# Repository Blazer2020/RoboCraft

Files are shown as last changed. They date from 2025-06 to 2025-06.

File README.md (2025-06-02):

# 🤖 Autonomous Robot – Robot Design Module

This project features an autonomous mobile robot developed by **Team RoboCraft** for the **Hawkins Interdimensional Challenge 2024**, hosted by the Department of Electronic and Telecommunication Engineering, University of Moratuwa.

The robot was designed to complete a series of 8 challenging tasks involving line following, color tracking, box manipulation, portal navigation, and terrain traversal — all under fully autonomous control. Built using an Arduino Mega, JGA25 encoder motors, Reykha IR sensor array, and a 3D-printed chassis, the robot runs on an onboard 11.1V Li-ion battery and uses intelligent decision-making to adapt to each task without any external input.

---

## 🛠 Robot Overview

| Component | Specification |
|---|---|
| **Microcontroller** | Arduino Mega 2560 |
| **Motors** | JGA25 DC Encoder Motors (×2) |
| **Motor Driver** | L298N Dual H-Bridge |
| **Gripper** | SG90 Servo Motor |
| **Chassis** | 3D Printed Body (240mm × 180mm footprint) |
| **Sensors** | Reykha Analog IR Line Sensor Array |
| **Battery** | 11.1V 400mAh Li-ion Battery (onboard power) |
| **Indicators** | Onboard LEDs (task status and feedback) |

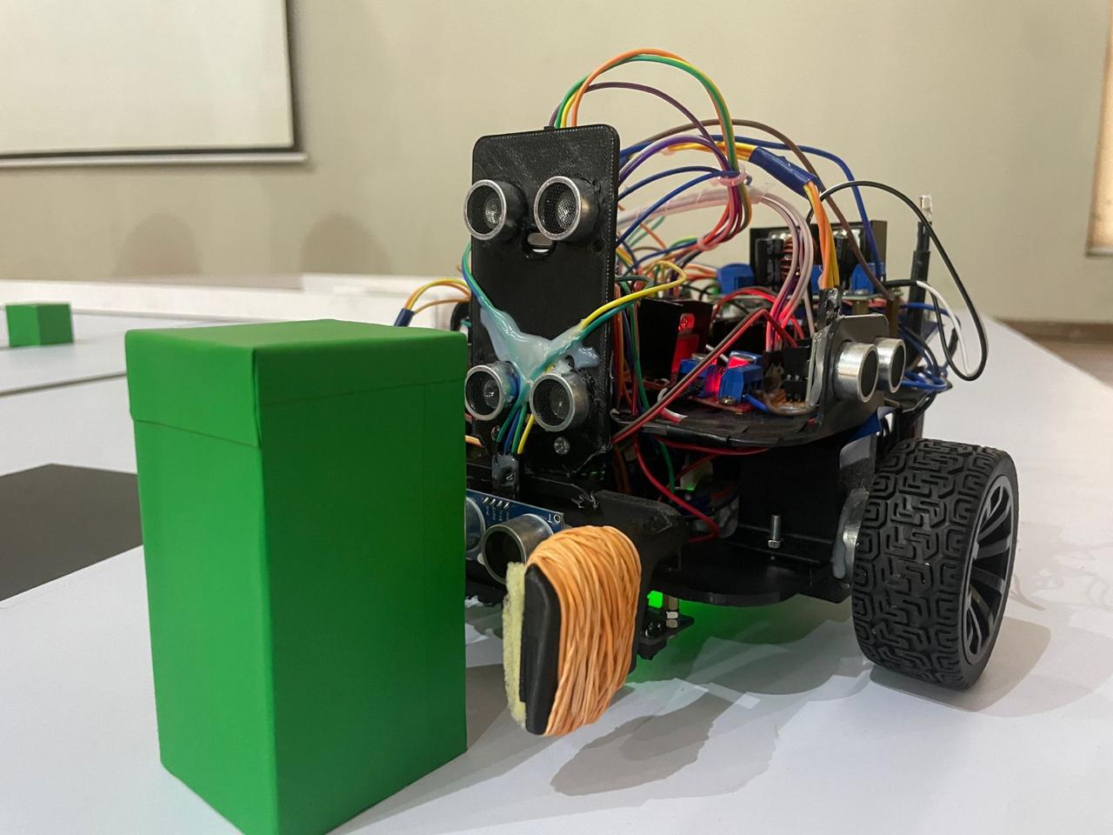
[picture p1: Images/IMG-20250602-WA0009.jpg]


---

## 🎯 Challenge Tasks

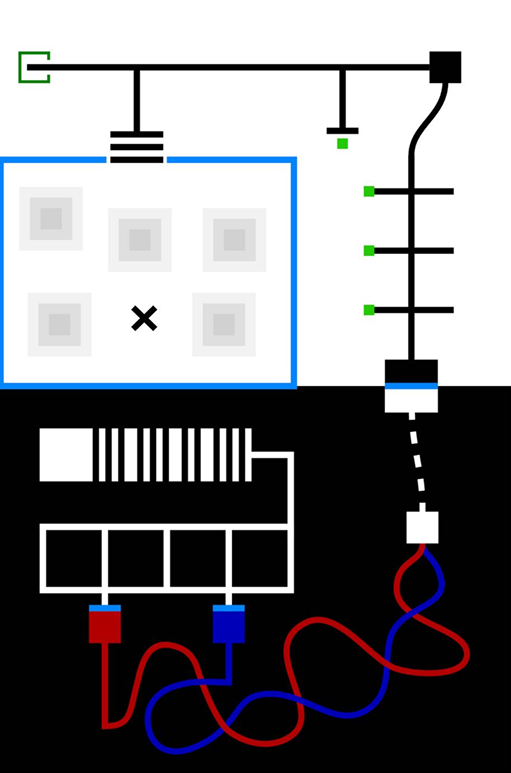
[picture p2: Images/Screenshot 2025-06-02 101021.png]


| Task No. | Task Name | Description |
|---|---|---|
| **1** | Line Width Detection | Follow white lines of varying widths (3cm = 0, 6cm = 1) to extract a binary code |
| **2** | Virtual Box Maze Navigation | Simulate grabbing and transporting a virtual box with restricted movement |
| **3** | Color Line Following | Follow Red or Blue line based on the checkpoint from Task 2 |
| **4** | Dashed Line Navigation | Track a dashed white line leading to the portal area |
| **5** | Portal Timing Challenge | Time movement to pass through a 5s open/5s close gate without collision |
| **6** | Box Sorting | Arrange boxes of different heights in order (asc/desc based on prior path) |
| **7** | Box Insertion | Follow a line to insert a small box into a chamber hole |
| **8** | Coin Drop on Magnetic Spot | Drop a 2-rupee coin on an ‘X’ mark over uneven terrain to complete the run |

---

## 🧩 SolidWorks Model Previews

The robot's mechanical structure was designed in **SolidWorks** to ensure precise fitting of components and smooth task execution. Below are some rendered previews from the CAD models.

| View | Preview |
|---|---|
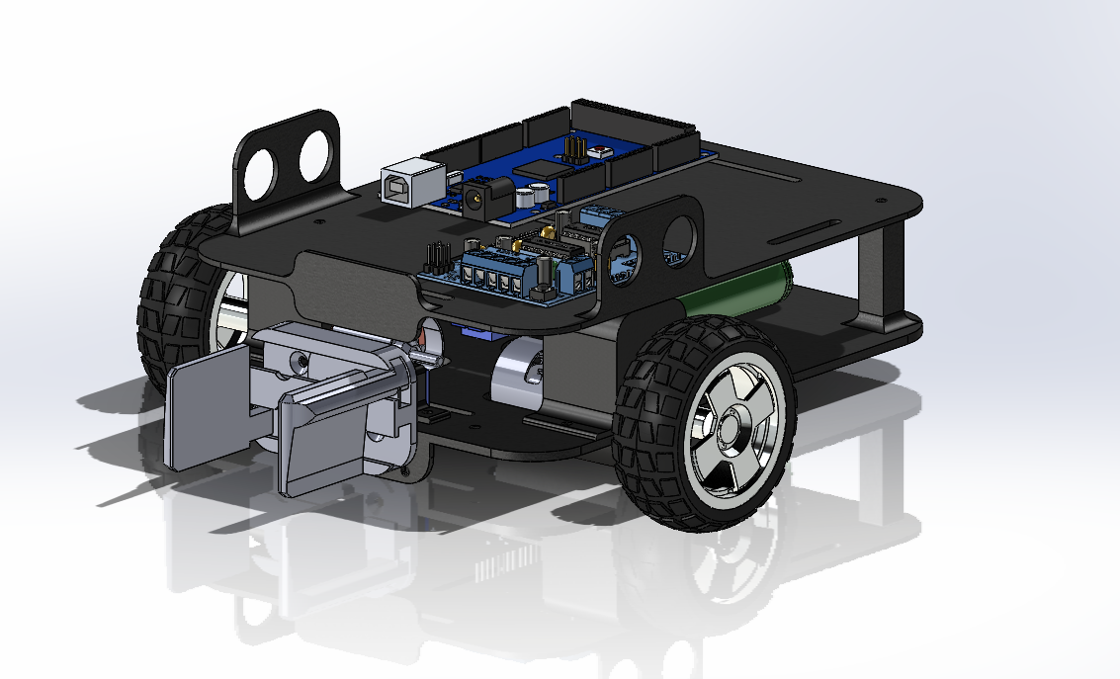
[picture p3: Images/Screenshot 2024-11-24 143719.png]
| **Front View** |   |
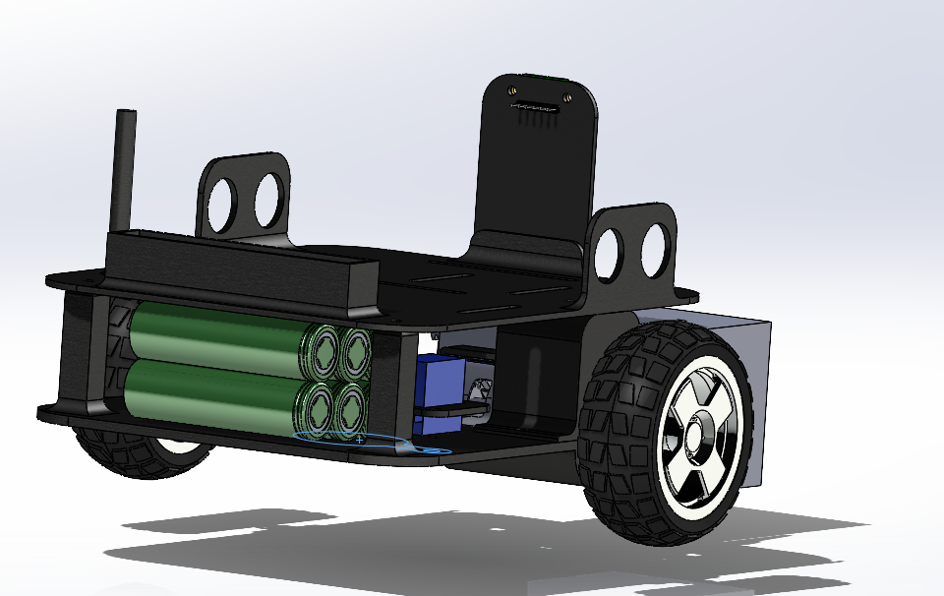
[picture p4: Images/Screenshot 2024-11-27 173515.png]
| **Rear View** |  |
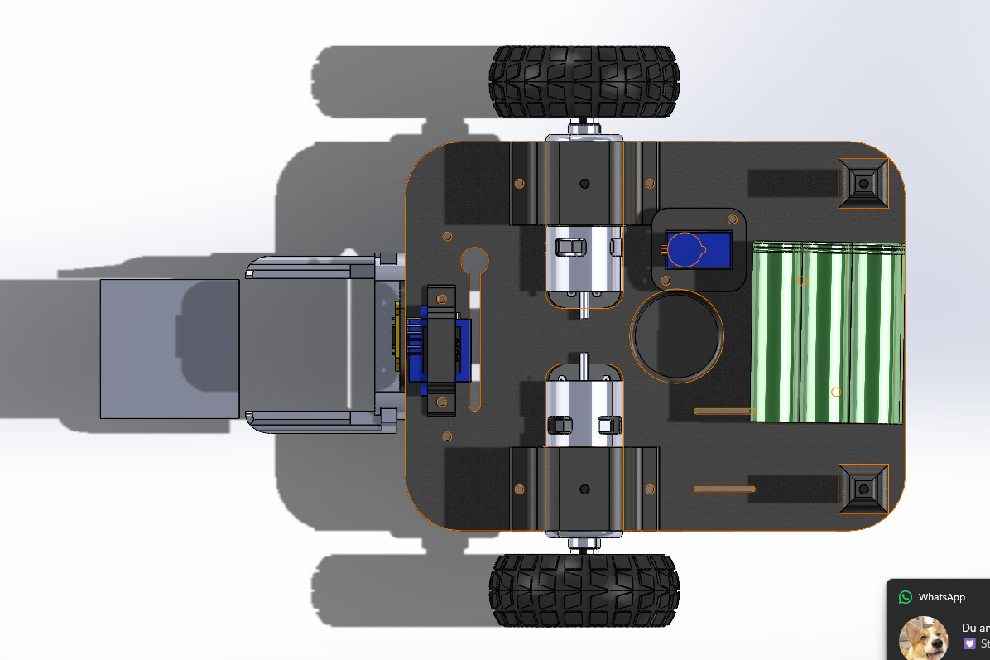
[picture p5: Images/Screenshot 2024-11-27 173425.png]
| **Top View** |  |
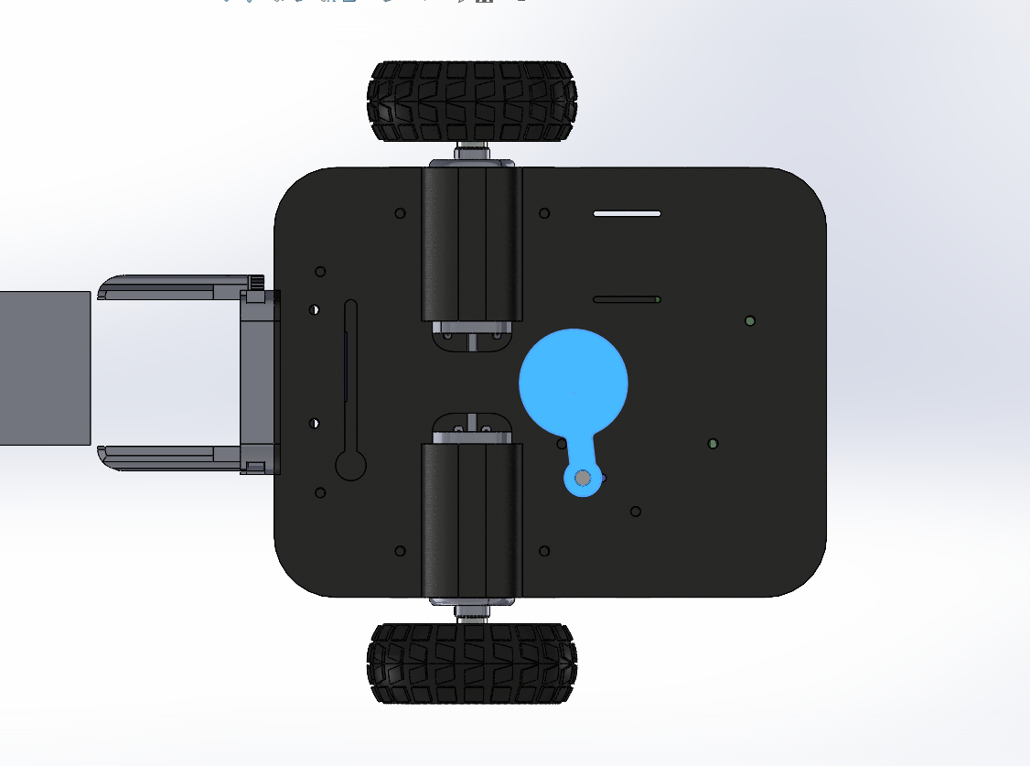
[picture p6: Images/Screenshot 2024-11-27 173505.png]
| **Bottom View** |  |
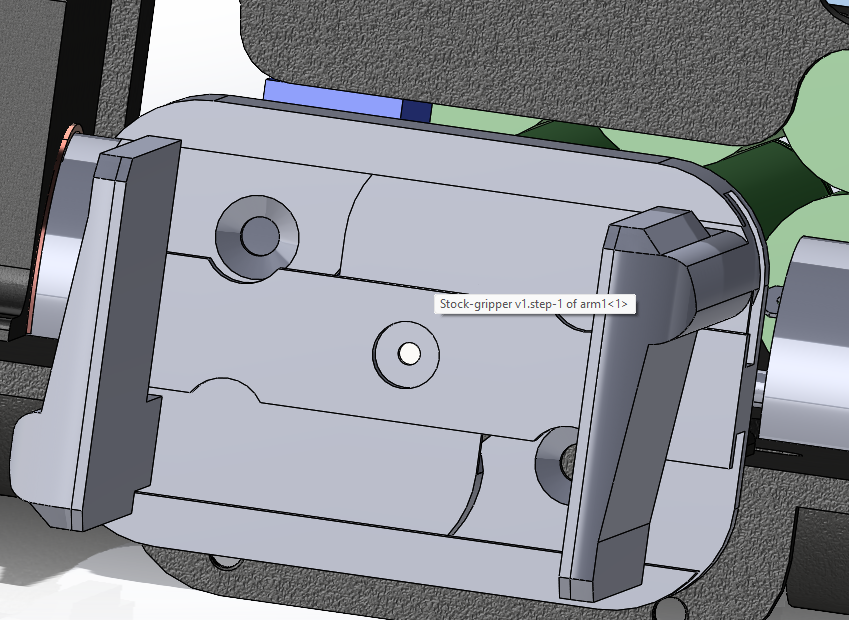
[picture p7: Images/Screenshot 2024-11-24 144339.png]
| **Gripper Design** |   |

> STL files and full CAD assemblies are available in the [`/STL files`](./STL files) folder.

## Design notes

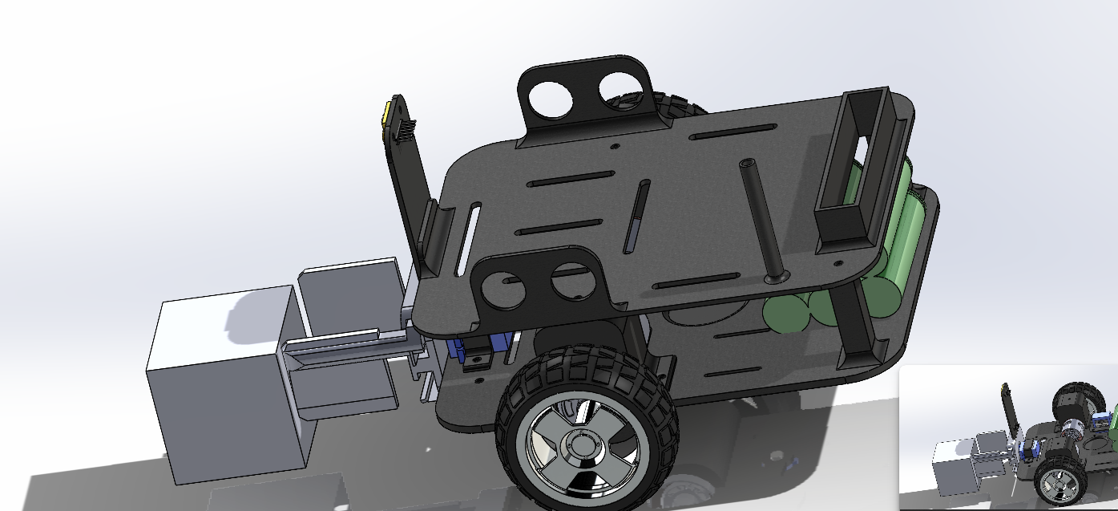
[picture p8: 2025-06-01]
Images/Screenshot 2024-11-27 173442.png

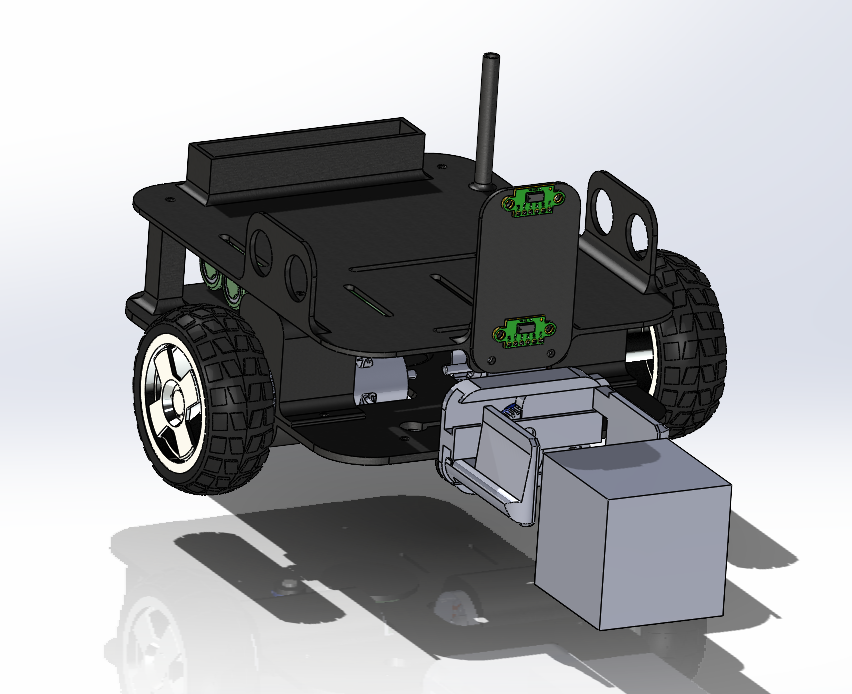
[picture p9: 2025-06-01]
Images/Screenshot 2024-11-27 173455.png

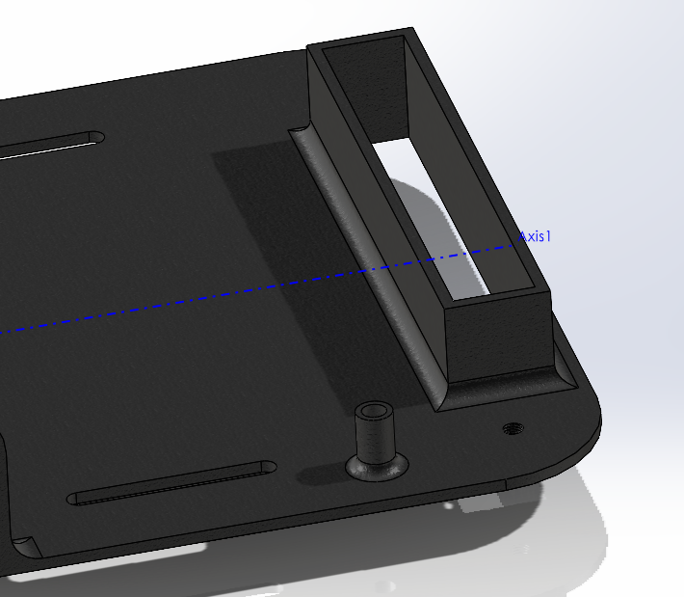
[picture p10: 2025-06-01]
Images/Screenshot 2024-11-27 163026.png

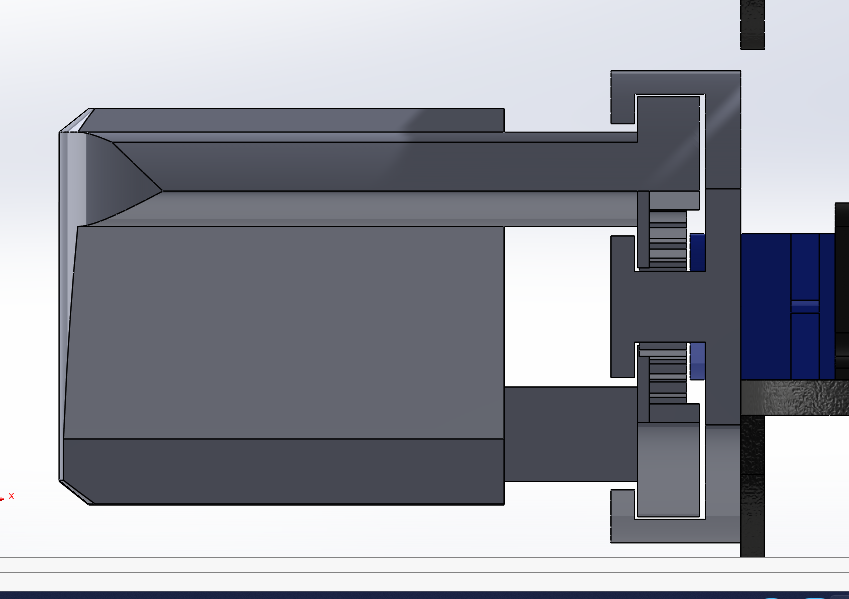
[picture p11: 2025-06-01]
Images/Screenshot 2024-11-24 144031.png

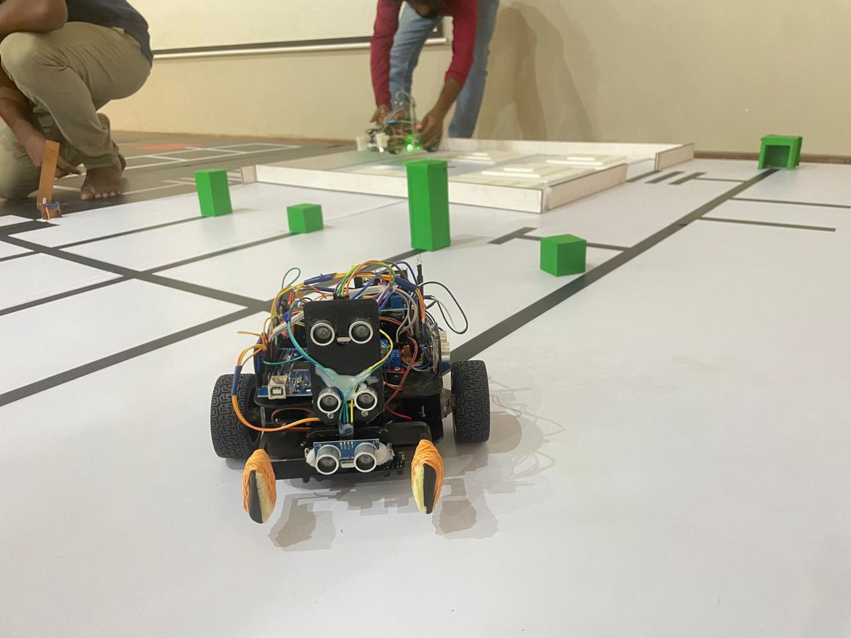
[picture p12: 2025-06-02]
Images/IMG-20250602-WA0007.jpg

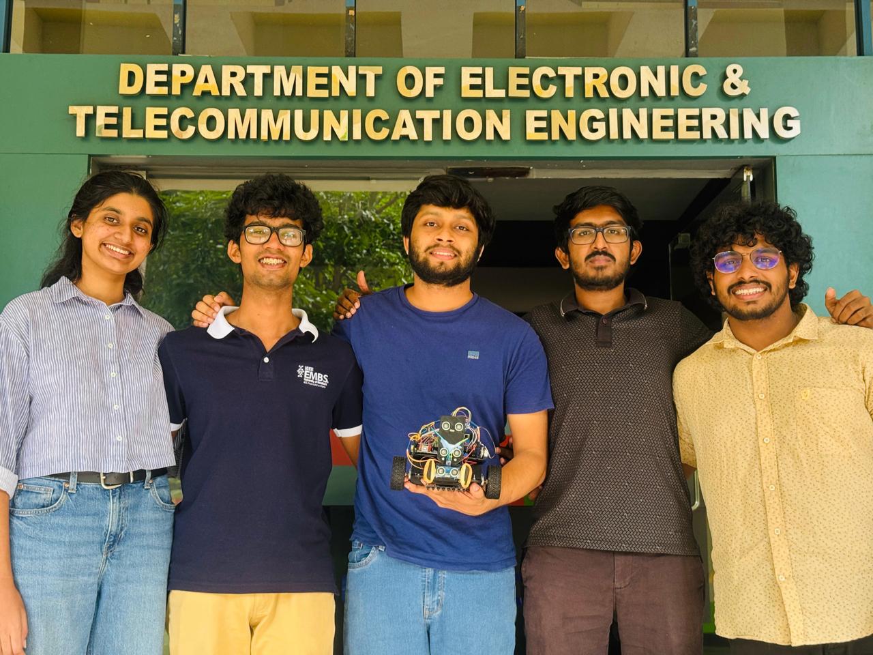
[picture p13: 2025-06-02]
Images/IMG-20250602-WA0006.jpg

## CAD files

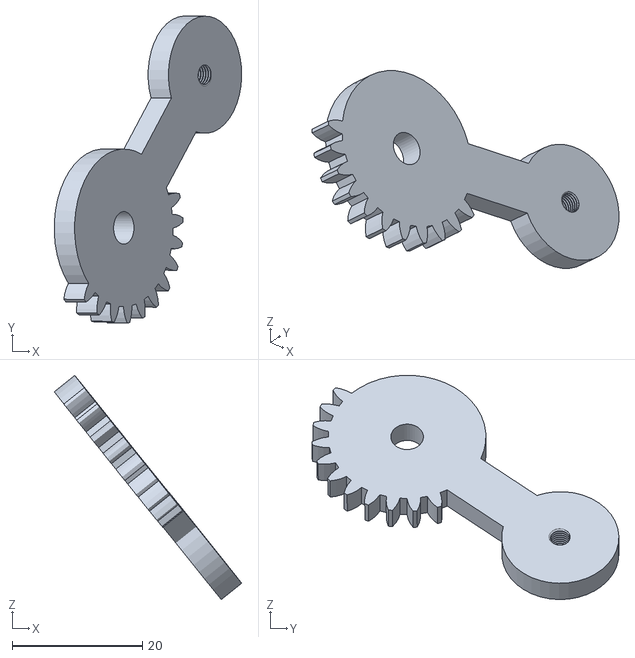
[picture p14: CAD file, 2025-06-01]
STL files/arm/weel1.STL
28.8 x 47.1 x 34.4

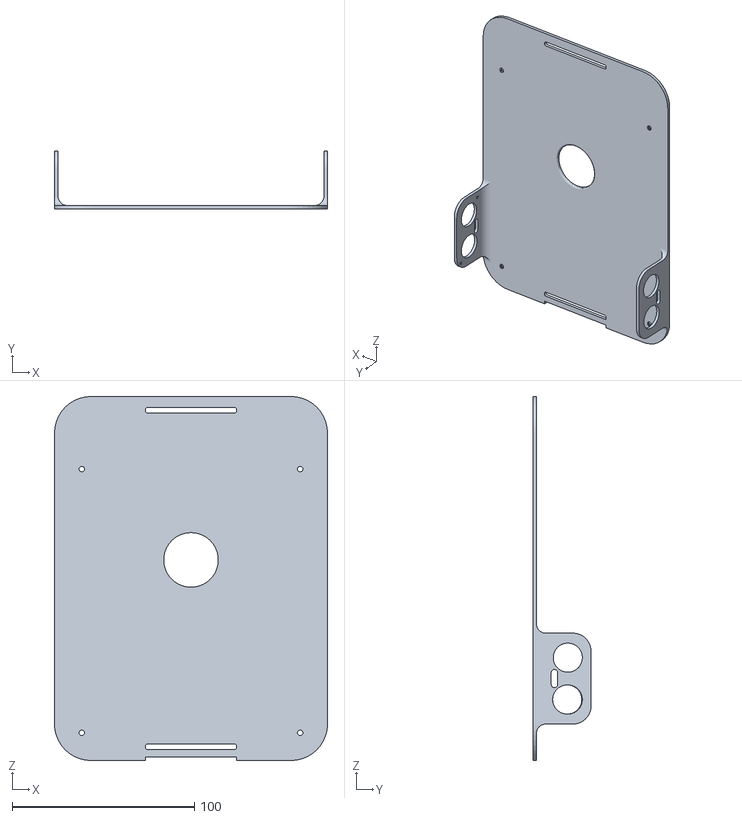
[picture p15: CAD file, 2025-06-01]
STL files/top.STL
150.0 x 32.0 x 200.0

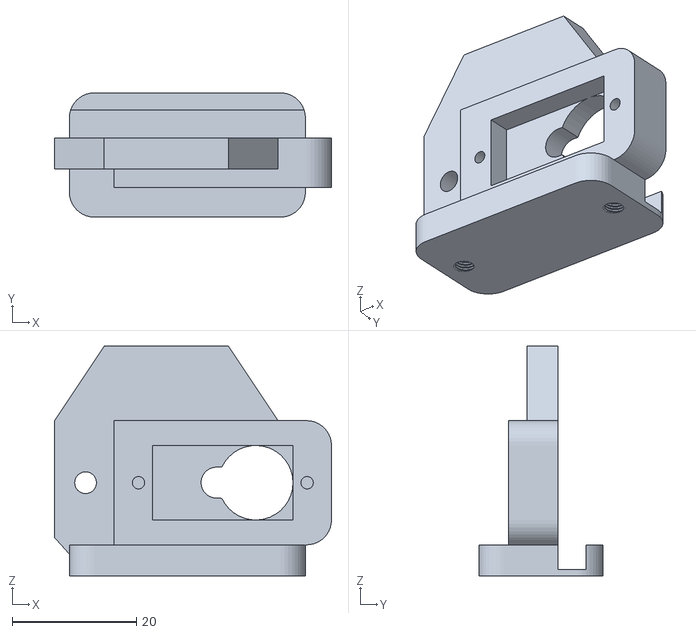
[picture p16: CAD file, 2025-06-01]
STL files/arm/Gripper base.STL
44.6 x 20.0 x 37.0

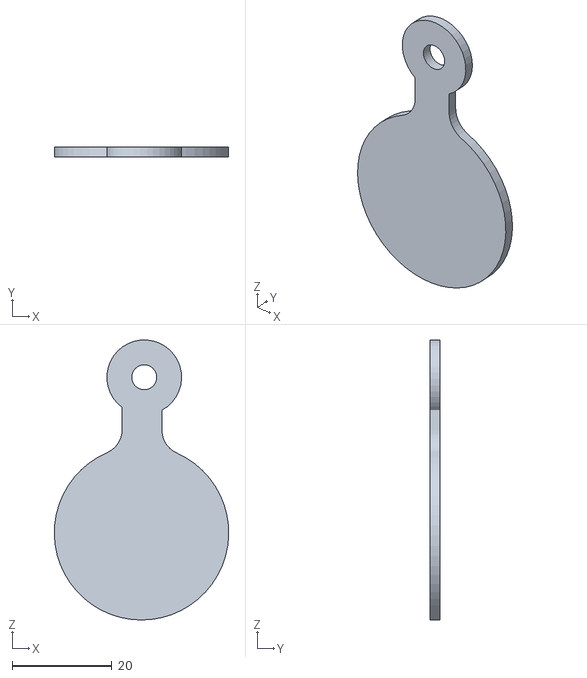
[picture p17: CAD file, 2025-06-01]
STL files/trap lid.STL
35.0 x 2.00 x 56.2

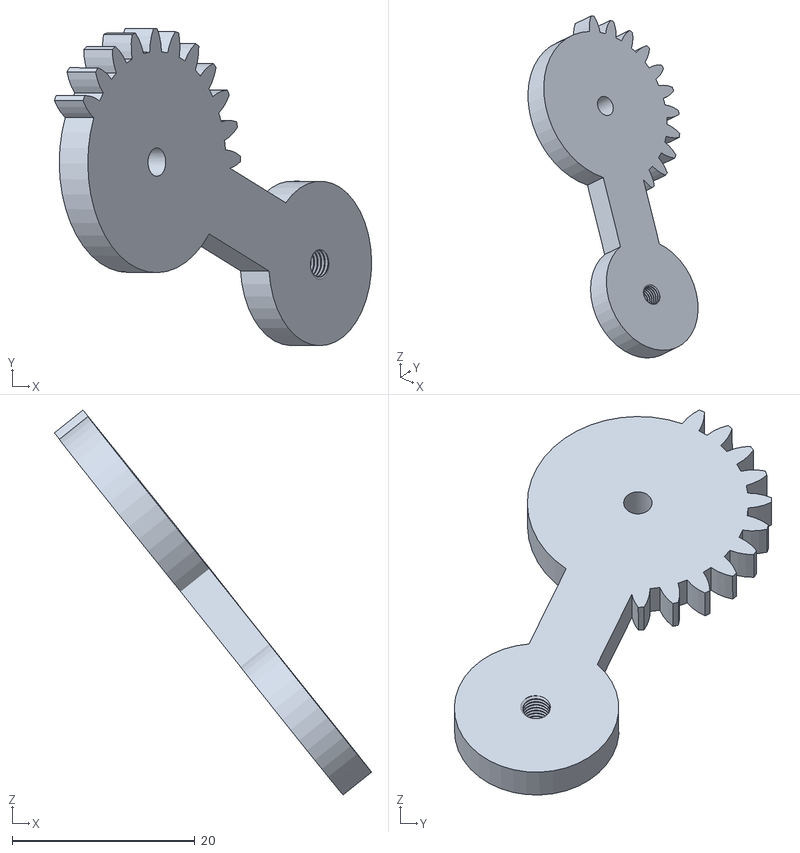
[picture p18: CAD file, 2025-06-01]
STL files/arm/weel2.STL
34.7 x 34.7 x 42.1

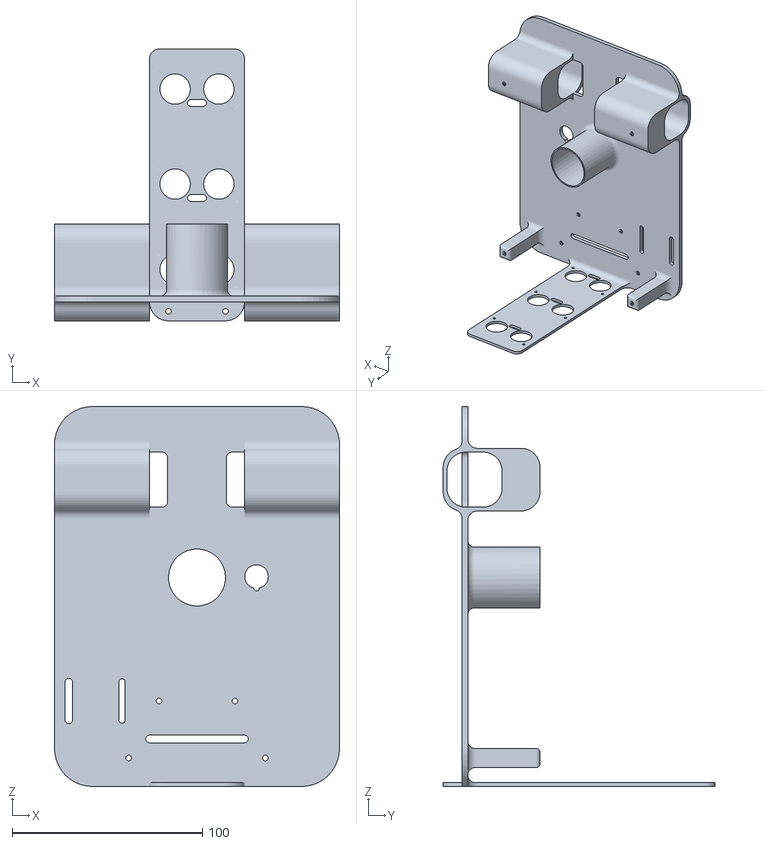
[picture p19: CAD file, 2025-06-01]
STL files/Base.STL
150.0 x 143.0 x 200.0

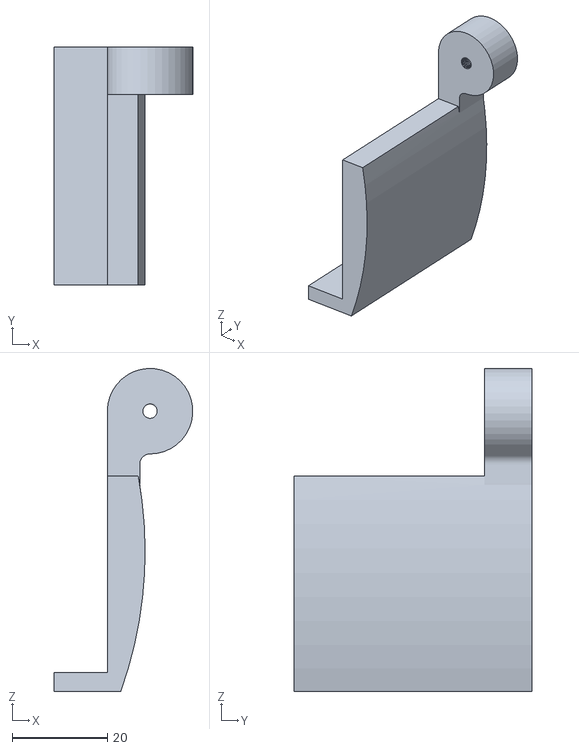
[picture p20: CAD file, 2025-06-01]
STL files/arm/hand1.STL
29.2 x 50.0 x 68.0

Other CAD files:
STL files/arm/hand2.STL

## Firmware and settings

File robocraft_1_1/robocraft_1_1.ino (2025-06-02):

#include <util/atomic.h>
#include <LinkedList.h>
#include <BeeLineSensorPro.h>
#include <Servo.h>

Servo myservo;
Servo trapdoor;

int dul=0;
int countP;
int countPP;
int t1,t4,t6;
int counttask2 = 0; int countsix = 0; int countsix2 = 0; int countsix3 = 0;
int counttask2task2 = 0;
int p = 0,count =0,q=0,r=0,a=0;
unsigned long linetime = 1;
LinkedList<int> barcode;
int startingturn=0;
int start_pos,end_pos,difference,number;
int speed = 100;// Update based on your connection
const int echoPin = 48;
const int trigPin = 49;   // Update based on your connection
long duration;
float distance;
bool gate;
int num;
bool order = false;

int task3=0;
int task4=0;
int leftlinefollowing=0;
int rightlinefollowing=0;
int task4linecount=0;
int stopcount=0;
int starttask=0;

int linefollowingcount=0;
int linefollowingcount2=0;
int allblack=0;
int allblack2=0;
int blackcount=0;
int task7_1=0;
int task7_2=0;
int whitecount=0;
int black=0;

unsigned long dstart, dend, ddifference,dtime=0;

bool height1, height2, height3;
int Height = 0 ,  Height2 = 0, Height3 = 0,Height8;
float gap;

const int trigPin1 = 51;
const int echoPin1 = 50;
const int trigPin2 = 53;
const int echoPin2 = 52;
const int trigPin3 = 47;   // New ultrasonic sensor for height 3
const int echoPin3 = 46;   // New ultrasonic sensor for height 3


//ColorLineFollowing
float kP=0.03; //kp=0.05-Black //white 0.008
float kD=0;
float last_value=0;
BeeLineSensorPro sensor = BeeLineSensorPro((unsigned char[]){ A0,A1,A2,A3,A4,A5,A6,A7},LINE_WHITE);
int s0,s1,s2,s3,s4,s5,s6,s7;
#define M1 7
#define M1pwm 6
#define M2 9
#define M2pwm 8
int i;
int colorlinecorrection=0;

// A class to compute the control signal
class SimplePID{
  private:
    float kp, kd, ki, umax; // Parameters
    float eprev, eintegral; // Storage

  public:
  // Constructor
  SimplePID() : kp(1), kd(0.025), ki(0), umax(255), eprev(0.0), eintegral(0.0){}

  // A function to set the parameters
  void setParams(float kpIn, float kdIn, float kiIn, float umaxIn){
    kp = kpIn; kd = kdIn; ki = kiIn; umax = umaxIn;
  }

  // A function to compute the control signal
  void evalu(int value, int target, float deltaT, int &pwr, int &dir){
    // error
    int e = target - value;
  
    // derivative
    float dedt = (e-eprev)/(deltaT);
  
    // integral
    eintegral = eintegral + e*deltaT;
  
    // control signal
    float u = kp*e + kd*dedt + ki*eintegral;
  
    // motor power
    pwr = (int) fabs(u);
    if( pwr > umax ){
      pwr = speed;
    }
  
    // motor direction
    dir = -1;
    if(u<0){
      dir = 1;
    }
  
    // store previous error
    eprev = e;
  }
  
};

// How many motors
#define NMOTORS 2

// Pins
const int enca[] = {2,18};
const int encb[] = {3,19};
//const int pwm[] = {9,13};
const int in1[] = {M2pwm,M1pwm};
const int in2[] = {M2,M1};

// Globals
long prevT = 0;
volatile int posi[] = {0,0};

// PID class instances
SimplePID pid[NMOTORS];

void setup() {
  Serial.begin(9600);
  pinMode(M1, OUTPUT);
  pinMode(M1pwm, OUTPUT);
  pinMode(M2, OUTPUT);
  pinMode(M2pwm, OUTPUT);
  pinMode(13,OUTPUT);

  pinMode(trigPin, OUTPUT);
  pinMode(echoPin, INPUT);


  for(int k = 0; k < NMOTORS; k++){
    pinMode(enca[k],INPUT);
    pinMode(encb[k],INPUT);
    //pinMode(pwm[k],OUTPUT);

    pid[k].setParams(1,0,0,255);
  }
  
  attachInterrupt(digitalPinToInterrupt(enca[0]),readEncoder<0>,RISING);
  attachInterrupt(digitalPinToInterrupt(enca[1]),readEncoder<1>,RISING);
  pinMode(22,INPUT);pinMode(23,INPUT);pinMode(24,INPUT);pinMode(25,INPUT);pinMode(26,INPUT);pinMode(27,INPUT);pinMode(28,INPUT);pinMode(29,INPUT);
  //Serial.println("target pos");


  pinMode(trigPin1, OUTPUT);
  pinMode(echoPin1, INPUT);
  pinMode(trigPin2, OUTPUT);
  pinMode(echoPin2, INPUT);
  pinMode(trigPin3, OUTPUT);
  pinMode(echoPin3, INPUT);
  pinMode(30, OUTPUT);
  pinMode(33, OUTPUT);
  pinMode(42, OUTPUT);
  pinMode(32,INPUT_PULLUP);
  pinMode(34,INPUT_PULLUP);
  pinMode(37,INPUT_PULLUP);
  pinMode(38,INPUT_PULLUP);
  pinMode(40,INPUT_PULLUP);  

  delay(5000);
  //digitalWrite(13,HIGH);


  myservo.attach(12);  
  myservo.write(30);
  trapdoor.attach(4);
  trapdoor.write(0);

}

void loop() {   
  //height();
  //gatedetector();  
  //colorline();
  //dashedline();
  // Example condition
  //Serial.println("trying");
  //grab();
  //Serial.println("ohase2");
  //grelease();
  //height();
  //loopfollowfull();
  //mdrive(0,0);
  //delay(1000);
  //heightnew();
  //Height2=Height2-14;
  //go(Height2);
  //back(15);
  //turnleftfull();
  //loopfollow();
  //mdrive(0,0);
  //delay(1000);
  //back(20);
  //mdrive(0,0);
  //delay(100000);
  //colorline();
  //dashedline();
  //loopfollowfull();
  //mdrive(0,0);
  //back(20);
  //go(Height2);
  //mdrive(0,0);
  //delay(100000);
    // Other loop operations...
  //processLineFollowing();
  //gatetimer();
  //if(r==0){
    //four();
    //r++;
  //}
  //mdrive(0,0);
  //sensor.setColorMode(LINE_BLACK);
  //tasksixascending1();
  /*for(int i = 22 ; i<30 ;i++){
  Serial.print(digitalRead(i));
  }
  Serial.println();
  mdrive(0,0);*/
  //delay(10000);
  //forward();
  //gatedetector();
  //reverse();
  //delay(5000);
  //reverse();
  //delay(500000);
  /*processLineFollowing();
  if(checkrightsensors()){
    mdrive(0,0);
    forward();
    turnright();
    delay(5000);
  }*/
  //turnrightfull();
  //delay(5000);
  //turnleftfull();
  //reverse();
  //mdrive(0,0);
  //delay(5000);
  //correction();

  //Serial.println(digitalRead(40));
  //delay(1000);

  if(count==0 && digitalRead(40) == LOW){
    while(count < 3){
    // set target position
      int target[NMOTORS];
      target[0] = 6000;
      target[1] = 6000;

    // time difference
    long currT = micros();
    float deltaT = ((float) (currT - prevT))/( 1.0e6 );
    prevT = currT;

    // Read the position in an atomic block to avoid a potential misread
    int pos[NMOTORS];
    ATOMIC_BLOCK(ATOMIC_RESTORESTATE){
      for(int k = 0; k < NMOTORS; k++){
        pos[k] = posi[k];
      }
    } 
  
      // loop through the motors
    for(int k = 0; k < NMOTORS; k++){
      int pwr, dir;
      // evaluate the control signal
      pid[k].evalu(pos[k],target[k],deltaT,pwr,dir);
      // signal the motor
      
      if(k==0){
        setMotor(dir,pwr-2.5,in1[k],in2[k]);
      }
      else{
        setMotor(dir,pwr,in1[k],in2[k]);
      }
    }

    for(int k = 0; k < NMOTORS; k++){
      Serial.print(target[k]);
      Serial.print(" ");
      Serial.print(pos[k]);
      Serial.print(" ");
    }
      Serial.println();
    int b = analogRead(A3);
    start_pos  = pos[0];
    if(digitalRead(22) == 0 and digitalRead(29)==0 ){
      start_pos = pos[0];
      //Serial.println(start_pos);
      while(digitalRead(22) == 0 and digitalRead(29)==0 ){

      }
      ATOMIC_BLOCK(ATOMIC_RESTORESTATE){
        for(int k = 0; k < NMOTORS; k++){
          pos[k] = posi[k];
        }
      } 
      end_pos = pos[0];
      //Serial.println(end_pos);
      difference = end_pos - start_pos;
      //Serial.println(difference);
      
    }

    if(q==0){
      q++;
      difference=0;
    }
    else{
          if (difference > 200 ){
            barcode.add(1);
            difference = 0;
            count = 0;

          }
          if(difference != 0 && difference <200 && difference >80){
            barcode.add(0);
            difference = 0;
            count++;
          }
    }
    setMotor(1, 0 , 6, 7 );
    setMotor(1, 0 , 8 , 9 );
  }
  // Barcode Calculate
    if(p == 0){
    
      for (int k = barcode.size() - 4; k >= 0; k--) {
        if (p < 2) {
          number += (1 << p) * barcode.get(k);  // Use bit shifting instead of pow
          p++;
        } 
        else {
          number += (1 << p) * barcode.get(k);  // Use bit shifting here as well
          p++;
        }
      }
    }
    count++;
    
  
    if (count == 4){
      Serial.print("number ");
      Serial.println(number);
      delay(1000);
      setMotor(1, 0 , 6, 7 );
      setMotor(1, 0 , 8 , 9 );
      count++;
      loopfollowfull();
  }
  
  //reverse();
  //forward();
  //turnleft();

  while(r<1){
    processLineFollowing();
    if (checkrightsensors()){
      mdrive(0,0);
      delay(1000);
      forward();
      turnright();
      r++;
    }
  }
  
  if(r==1){
    num = number % 5; 
    if(num==0){  
      zero();
    }
    if(num==1){  
      one();
    }
    if(num==2){  
      two();
    }
    if(num==3){  
      three();
    }
    if(num==4){  
      four();
    }
    r++;
    forward();
    mdrive(0,0);
    delay(1000);
  }
   

  //if(r==2){
    //colorline();
    //dashedline();
    //r++;
  //}
    if(r==2 ){
      colorline();
      r++;
    }
  }  
  else{
    r=3;
  }
  if(r==3 && digitalRead(38)==LOW){
    task3=1;
    dashedline();
    gatetimer();
    delay(1500);
    go(40);
    
    mdrive(0,0);
    r++;
  }
  else{
    r=4;
  }

  sensor.setColorMode(LINE_BLACK);
  if(r==4 && digitalRead(37)==LOW){
    if(order){
      tasksixascending1();
      tasksixascending2();
      tasksixascending3();
      chamber1();
      r++;
      mdrive(0,0);    
    }
    else{
      tasksixascending11();
      tasksixascending22();
      tasksixascending33();
      r++;
      chamber1();
      mdrive(0,0);     
    }
  }
  else{
    r=5;
  }
  sensor.setColorMode(LINE_BLACK);
  if(r==5 && digitalRead(34) == 0){
    while(dul < 3){
    processLineFollowing();
    if((checkallsensorsB() or checkrightsensorsB() or checkallsensorsB()) && dul ==0){
      forward();
      loopfollowfull();
      dul++;
    }
    if((checkallsensorsB() or checkrightsensorsB() or checkallsensorsB()) && dul ==1){
      mdrive(0,0);
      delay(1000);     
      forward();

      turnright();
      delay(1000);
      loopfollowB();
      forwardminisix();
      mdrive(0,0);
      delay(1000);     
      forwardminisix();
      mdrive(0,0);
      delay(2000);
      reversesix();
      mdrive(0,0);
      delay(1000);
      reversesix();
      mdrive(0,0);
      delay(1000);
      turnrightfull();
      loopfollowfull();
      mdrive(0,0);
      dul++;
      }
    if((checkallsensorsB() or checkrightsensorsB() or checkallsensorsB()) && dul ==2){
      mdrive(0,0);
      delay(1000);
      forward();
      turnright();
      loopfollowfull();
      mdrive(0,0);
      delay(1000);
      dul++;
    }
    }
    r++;
  
  }
  else{
    r=6;
  }
  if(r==6 && digitalRead(32) == 0){
    chamber2();
    mdrive(0,0);
    while ((digitalRead(29)==1) or (digitalRead(28)==1) or (digitalRead(27)==1) or (digitalRead(26)==1) or
    (digitalRead(25)==1) or (digitalRead(24)==1) or (digitalRead(23)==1) or (digitalRead(22)==1)){
      turnrighthalf();
      mdrive(80,80);
      delay(4500);
      turnlefthalf();
      mdrive(80,80);

      }
    go(10);
    openDoor;
    r++;
  }
  
  

}


void setMotor(int dir, int pwmVal, int in1, int in2){
  
  if(dir == 1){
    analogWrite(in1,pwmVal);
    digitalWrite(in2,LOW);
  }
  else if(dir == -1){
    digitalWrite(in1,LOW);
    analogWrite(in2,pwmVal);
  }
  else{
    digitalWrite(in1,LOW);
    digitalWrite(in2,LOW);
  }  
}

template <int j>
void readEncoder(){
  int b = digitalRead(encb[j]);
  if(b > 0){
    posi[j]++;
  }
  else{
    posi[j]--;
  }
}
void turnright(){
    mdrive(0,0);
    int pos[NMOTORS];
    ATOMIC_BLOCK(ATOMIC_RESTORESTATE){
      for(int k = 0; k < NMOTORS; k++){
        posi[k]=0;
      }
    } 
    int target[NMOTORS];
    target[0] = 620+200;
    target[1] = -620-200;
    while((posi[0]<target[0]-70-200)){
    // time difference
      long currT = micros();
      float deltaT = ((float) (currT - prevT))/( 1.0e6 );
      prevT = currT;

    // Read the position in an atomic block to avoid a potential misread
    int pos[NMOTORS];
    ATOMIC_BLOCK(ATOMIC_RESTORESTATE){
      for(int k = 0; k < NMOTORS; k++){
        pos[k] = posi[k];
      }
    } 
  
      // loop through the motors
    for(int k = 0; k < NMOTORS; k++){
      int pwr, dir;
      // evaluate the control signal
      pid[k].evalu(pos[k],target[k],deltaT,pwr,dir);
      // signal the motor
      setMotor(dir,pwr,in1[k],in2[k]);
    }

    for(int k = 0; k < NMOTORS; k++){
      Serial.print(target[k]);
      Serial.print(" ");
      Serial.print(pos[k]);
      Serial.print(" ");
    }
      Serial.println();
    }
    setMotor(1, 0 , 6, 7 );
    setMotor(1, 0 , 8 , 9 );

}
void turnleft(){
    mdrive(0,0);
    int pos[NMOTORS];
    ATOMIC_BLOCK(ATOMIC_RESTORESTATE){
      for(int k = 0; k < NMOTORS; k++){
        posi[k]=0;
      }
    } 
    int target[NMOTORS];
    target[0] = -580-200;
    target[1] = 580+200;
    while((posi[1]<target[1]-200)){
    // time difference
    long currT = micros();
    float deltaT = ((float) (currT - prevT))/( 1.0e6 );
    prevT = currT;

    // Read the position in an atomic block to avoid a potential misread
    int pos[NMOTORS];
    ATOMIC_BLOCK(ATOMIC_RESTORESTATE){
      for(int k = 0; k < NMOTORS; k++){
        pos[k] = posi[k];
      }
    } 
  
      // loop through the motors
    for(int k = 0; k < NMOTORS; k++){
      int pwr, dir;
      // evaluate the control signal
      pid[k].evalu(pos[k],target[k],deltaT,pwr,dir);
      // signal the motor
      if(k==0){
        setMotor(dir,pwr,in1[k],in2[k]);
      }
      else{
        setMotor(dir,pwr,in1[k],in2[k]);
      }
    }

    for(int k = 0; k < NMOTORS; k++){
      Serial.print(target[k]);
      Serial.print(" ");
      Serial.print(pos[k]);
      Serial.print(" ");
    }
      Serial.println();
    }
    setMotor(1, 0 , 6, 7 );
    setMotor(1, 0 , 8 , 9 );

}
void forward(){
    int pos[NMOTORS];
    ATOMIC_BLOCK(ATOMIC_RESTORESTATE){
      for(int k = 0; k < NMOTORS; k++){
        posi[k]=0;
      }
    } 
    int target[NMOTORS];
    target[0] = 310+200;
    target[1] = 310+200;
    while(posi[0]<target[0]-20-200){
    // time difference
    long currT = micros();
    float deltaT = ((float) (currT - prevT))/( 1.0e6 );
    prevT = currT;

    // Read the position in an atomic block to avoid a potential misread
    int pos[NMOTORS];
    ATOMIC_BLOCK(ATOMIC_RESTORESTATE){
      for(int k = 0; k < NMOTORS; k++){
        pos[k] = posi[k];
      }
    } 
  
      // loop through the motors
    for(int k = 0; k < NMOTORS; k++){
      int pwr, dir;
      // evaluate the control signal
      pid[k].evalu(pos[k],target[k],deltaT,pwr,dir);
      // signal the motor
      setMotor(dir,pwr,in1[k],in2[k]);
    }

    for(int k = 0; k < NMOTORS; k++){
      Serial.print(target[k]);
      Serial.print(" ");
      Serial.print(pos[k]);
      Serial.print(" ");
    }
      Serial.println();
    }

}
int mdrive(int m1,int m2){
  if(m1>0){
    //m forward
    if (m1>255){
      m1=255;
    }
    digitalWrite(M1,HIGH);
    analogWrite(M1pwm,255-m1);
  }
  else{
    if (m1<-255){
      m1=-255;
    }
    digitalWrite(M1,LOW);
    analogWrite(M1pwm,m1*-1);
  }
  if(m2>0){
    //m forward
    if (m2>255){
      m2=255;
    }
    digitalWrite(M2,HIGH);
    analogWrite(M2pwm,255-m2);
  }
  else{
    if (m2<-255){
      m2=-255;
    }
    digitalWrite(M2,LOW);
    analogWrite(M2pwm,m2*-1);
  }
  

}
void processLineFollowing() {
  
  int err = sensor.readSensor(); //calculating the error // 

    for (int i = 0; i < 8; i++) {
    Serial.print(sensor.values[i]);
    Serial.print('\t');
    }
  //Serial.println(err); //printing the error value//
  
    int m1 = 80;
    int m2 = 80;
  
    int diff = err * kP + (err - last_value) * kD; // we will add this to one motor and subtract from other //
  
    last_value = err;
  //Serial.println(diff);    
  mdrive(m1 + diff, m2 - diff);
  Serial.println(diff); //printing the error value//

  
}
int checkallsensors(){
  bool allsensors;
  if(((digitalRead(29)==0)&&(digitalRead(22)==0)))
  {
    allsensors=true;
  }
  else{
    allsensors=false;
  }
  return allsensors;
}
int checkrightsensors(){
  bool rightsensors;
  //((digitalRead(43)==0)&&(digitalRead(42)==0)&&(digitalRead(41)==0)&&(digitalRead(40)==0)&&(digitalRead(36)==1))||
  if((digitalRead(29)==0)&&(digitalRead(28)==0)&&(digitalRead(27)==0)&&(digitalRead(26)==0)&&(digitalRead(25)==0)&&(digitalRead(22)==1))
    {
      rightsensors=true; 
    }
  else{
    rightsensors=false;
  }
  return rightsensors;
}

int checkleftsensors(){
  bool leftsensors;
  //((digitalRead(43)==1)&&(digitalRead(39)==0)&&(digitalRead(38)==0)&&(digitalRead(37)==0)&&(digitalRead(36)==0))||
  if((digitalRead(29)==1)&&(digitalRead(26)==0)&&(digitalRead(25)==0)&&(digitalRead(24)==0)&&(digitalRead(23)==0)&&(digitalRead(22)==0))
  {
    leftsensors=true;
  }
  else{
    leftsensors=false;
  }
  return leftsensors;
}

void forwardmini(){
    int pos[NMOTORS];
    ATOMIC_BLOCK(ATOMIC_RESTORESTATE){
      for(int k = 0; k < NMOTORS; k++){
        posi[k]=0;
      }
    } 
    int target[NMOTORS];
    target[0] = 50+200;
    target[1] = 50+200;
    while(posi[0]<target[0]-20-200){
    // time difference
    long currT = micros();
    float deltaT = ((float) (currT - prevT))/( 1.0e6 );
    prevT = currT;

    // Read the position in an atomic block to avoid a potential misread
    int pos[NMOTORS];
    ATOMIC_BLOCK(ATOMIC_RESTORESTATE){
      for(int k = 0; k < NMOTORS; k++){
        pos[k] = posi[k];
      }
    } 
  
      // loop through the motors
    for(int k = 0; k < NMOTORS; k++){
      int pwr, dir;
      // evaluate the control signal
      pid[k].evalu(pos[k],target[k],deltaT,pwr,dir);
      // signal the motor
      if(k==0){
        setMotor(dir,pwr,in1[k],in2[k]);
      }
      else{
        setMotor(dir,pwr,in1[k],in2[k]);
      }
    }

    for(int k = 0; k < NMOTORS; k++){
      //Serial.print(target[k]);
      //Serial.print(" ");
      //Serial.print(pos[k]);
      //Serial.print(" ");
    }
      //Serial.println();
    }
    setMotor(1, 0 , 6, 7 );
    setMotor(1, 0 , 8 , 9 );

}
void forwardtask3(){
    int pos[NMOTORS];
    ATOMIC_BLOCK(ATOMIC_RESTORESTATE){
      for(int k = 0; k < NMOTORS; k++){
        posi[k]=0;
      }
    } 
    int target[NMOTORS];
    target[0] = 200+200;
    target[1] = 200+30+200;
    while(posi[0]<target[0]-20-200){
    // time difference
    long currT = micros();
    float deltaT = ((float) (currT - prevT))/( 1.0e6 );
    prevT = currT;

    // Read the position in an atomic block to avoid a potential misread
    int pos[NMOTORS];
    ATOMIC_BLOCK(ATOMIC_RESTORESTATE){
      for(int k = 0; k < NMOTORS; k++){
        pos[k] = posi[k];
      }
    } 
  
      // loop through the motors
    for(int k = 0; k < NMOTORS; k++){
      int pwr, dir;
      // evaluate the control signal
      pid[k].evalu(pos[k],target[k],deltaT,pwr,dir);
      // signal the motor
      if(k==0){
        setMotor(dir,pwr,in1[k],in2[k]);
      }
      else{
        setMotor(dir,pwr,in1[k],in2[k]);
      }
    }

    for(int k = 0; k < NMOTORS; k++){
      //Serial.print(target[k]);
      //Serial.print(" ");
      //Serial.print(pos[k]);
      //Serial.print(" ");
    }
      //Serial.println();
    }
    setMotor(1, 0 , 6, 7 );
    setMotor(1, 0 , 8 , 9 );
}
void forwardtask2(){
    int pos[NMOTORS];
    ATOMIC_BLOCK(ATOMIC_RESTORESTATE){
      for(int k = 0; k < NMOTORS; k++){
        posi[k]=0;
      }
    } 
    int target[NMOTORS];
    target[0] = 200+200;
    target[1] = 200+200;
    while(posi[0]<target[0]-30-200){
    // time difference
    long currT = micros();
    float deltaT = ((float) (currT - prevT))/( 1.0e6 );
    prevT = currT;

    // Read the position in an atomic block to avoid a potential misread
    int pos[NMOTORS];
    ATOMIC_BLOCK(ATOMIC_RESTORESTATE){
      for(int k = 0; k < NMOTORS; k++){
        pos[k] = posi[k];
      }
    } 
  
      // loop through the motors
    for(int k = 0; k < NMOTORS; k++){
      int pwr, dir;
      // evaluate the control signal
      pid[k].evalu(pos[k],target[k],deltaT,pwr,dir);
      // signal the motor
      if(k==0){
        setMotor(dir,pwr,in1[k],in2[k]);
      }
      else{
        setMotor(dir,pwr,in1[k],in2[k]);
      }
    }

    for(int k = 0; k < NMOTORS; k++){
      //Serial.print(target[k]);
      //Serial.print(" ");
      //Serial.print(pos[k]);
      //Serial.print(" ");
    }
      //Serial.println();
    }
    setMotor(1, 0 , 6, 7 );
    setMotor(1, 0 , 8 , 9 );
}
void reversemini(){
    int pos[NMOTORS];
    ATOMIC_BLOCK(ATOMIC_RESTORESTATE){
      for(int k = 0; k < NMOTORS; k++){
        posi[k]=0;
      }
    } 
    int target[NMOTORS];
    target[0] = -250-200;
    target[1] = -250-200;
    while(posi[0]>target[0]+30+200){
    // time difference
    long currT = micros();
    float deltaT = ((float) (currT - prevT))/( 1.0e6 );
    prevT = currT;

    // Read the position in an atomic block to avoid a potential misread
    int pos[NMOTORS];
    ATOMIC_BLOCK(ATOMIC_RESTORESTATE){
      for(int k = 0; k < NMOTORS; k++){
        pos[k] = posi[k];
      }
    } 
  
      // loop through the motors
    for(int k = 0; k < NMOTORS; k++){
      int pwr, dir;
      // evaluate the control signal
      pid[k].evalu(pos[k],target[k],deltaT,pwr,dir);
      // signal the motor
      if(k==0){
        setMotor(dir,pwr-2.5,in1[k],in2[k]);
      }
      else{
        setMotor(dir,pwr,in1[k],in2[k]);
      }
    }

    for(int k = 0; k < NMOTORS; k++){
      //Serial.print(target[k]);
      //Serial.print(" ");
      //Serial.print(pos[k]);
      //Serial.print(" ");
    }
      //Serial.println();
    }
    setMotor(1, 0 , 6, 7 );
    setMotor(1, 0 , 8 , 9 );

}
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
